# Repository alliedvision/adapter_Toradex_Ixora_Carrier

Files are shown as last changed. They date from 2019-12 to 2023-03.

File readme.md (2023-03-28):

# Allied Vision Adapter Board CSI-2 for Toradex Ixora Carrier Board

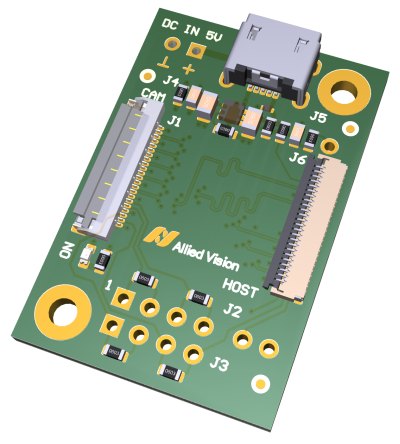
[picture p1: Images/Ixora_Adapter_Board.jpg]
toradex_ixora_adapter


This repository contains open hardware design files for an adapter board supporting the Allied Vision Alvium CSI-2 camera pinout to the Toradex Ixora Carrier Board, created by Allied Vision.
The board allows the user to interface with one Alvium MIPI CSI-2 compatible camera over a Flexible Flat Cable (FFC) connector.

You can also purchase the adapter from [Allied Vision](https://www.alliedvision.com/en/products/accessories/interface-connections/#!?cameraInterfacefilter=10) or from our [distributors](https://www.alliedvision.com/en/avt-locations/avt-distributors/).

## Getting Started

These instructions will get you a copy of the design files to make your own adapter boards for development and testing purposes. 
The board can be produced and assembled using the provided design files. Please take a look at the mechanical layers for more information regarding the PCB stackup recommended for fabrication. 

See our [website](https://www.alliedvision.com/en/support/technical-documentation/alvium-csi-2-documentation.html) for further documentation and installation guides of the finished boards.

### Prerequisites

* A running installation of Altium.
* A PCB producer & PCBA manufacturer or some soldering skills.
* One Toradex Ixora Carrier Board with an installed SOM
* One supported MIPI CSI-2 FPC cable
	* Allied Vision part numbers #12316, 12317, 12318
* [One Allied Vision Alvium CSI-2 camera](https://www.alliedvision.com/en/products/embedded-vision-cameras.html)

### Installing

Open the *CSI2-IXORA_Rev01.PrjPcb* project file in your Altium environment.

## Built With

* [Altium Designer 19](https://www.altium.com/altium-designer/de)
 
## License

This project is licensed under the MIT License - see the [LICENSE](LICENSE) file for details

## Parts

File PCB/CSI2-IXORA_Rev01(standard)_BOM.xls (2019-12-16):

 | Bill of Materials | CSI2-IXORA_Rev01
 | Project : | CSI2-IXORA
 | PCBA : |  | Revision : | 01
 | PCB : |  | Revision : | 01
 | Variant : | standard
 | Schematic : | CSI2-IXORA_Rev01 | Schematic.pdf
 | Placement : | CSI2-IXORA_Rev01 | Overlay.pdf
 | Report Date : | 26.11.2019 | 16:17
 | Alternative Parts :
Quantity | Designator | Comment | Footprint | Description | Manufacturer | Manufacturer Part Number | KHK Part Number
1 | C1 | 1n | C-0603_1.0 | Capacitor Ceramic SMD/0603/50V/X7R/10% | several | several | K8340038
2 | C2, C3 | 10u | C-0805_1.4 | Capacitor Ceramic SMD/0805/16V/X5R/10% | several | several | K8340151
1 | C4 | 100n | C-0603_1.0 | Capacitor Ceramic SMD/0603/50V/X7R/10% | several | several | K8340023
1 | D1 | GREEN | D-0603-LED | Chip LED green 430mcd | Würth | 150060GS75000 | 8172
1 | D2 | ESD9B5.0ST5G | D-SOD923 | DIODE TVS; 400W; 5.8-7.8V; BIDIRECT | ON Semiconductor | ESD9B5.0ST5G | 7250
1 | J1 | CON FFC22_Inverted | J-FH55-22S-0.5SH - Inverted Pins | FFC Connector 0.5mm shielded | Hirose | FH55-22S-0.5SH | 10357
2 | J2, J3 | NL | CON 1x4 RM2.54 | Stiftleiste; 1x4; 2.54mm; gerade
1 | J4 | NL | CON 1x2 RM2.54 | Stiftleiste; 1x2; 2.54mm; gerade
1 | J5 | USB 2.0 Typ B 90° | J-629105150521 | Micro USB 2.0 Typ B 90° | WE | 629 105 150 521 | 14360
1 | J6 | CON FFC24 | J-687124182122 | FFC Connector 0.5mm | Würth | 687124182122 | 14361
1 | LA1 | LABEL 7x7mm | PCB LABEL 7x7 | LABEL 7x7mm | several | several
3 | MRK1, MRK2, MRK3 | Marker Single Layer | PCB_Marker_Pad_top | Position Marker for PCBs
1 | PCB1 | 14276-01 |  | PCB ML04 | several | 14276-01 | 14276-01
1 | R1 | 3k3 | R-0603_0.6 | Standard Resistor SMD/0603/1%/100mW/TK100 | several | several | K8250070
1 | R2 | 1M | R-0603_0.6 | Standard Resistor SMD/0603/1%/100mW/TK100 | several | several | K8250058
4 | R3, R4, R6, R7 | 0R0 | R-0603_0.6 | Standard Resistor SMD/0603/1%/100mW/TK200, Standard Resistor SMD/0603/1%/100mW/TK100 | several | several | K8250041
1 | R5 | 51k | R-0603_0.6 | Standard Resistor SMD/0603/1%/100mW/TK100 | several | several | K8250156
1 | R8 | 270k | R-0603_0.6 | Standard Resistor SMD/0603/1%/100mW/TK100 | several | several | K8250170
2 | R9, R10 | NL | R-0603_0.6 | Standard Resistor SMD/0603/1%/100mW/TK200
1 | U1 | TPS25200DRVT | IC-DFN06_2.0x2.0x0.8 | IC/PWR/LOADSW;2V5-6V5;2A5;0R099/6-WDFN/2x2x0.8mm | Texas Instruments | TPS25200DRVT | 14277

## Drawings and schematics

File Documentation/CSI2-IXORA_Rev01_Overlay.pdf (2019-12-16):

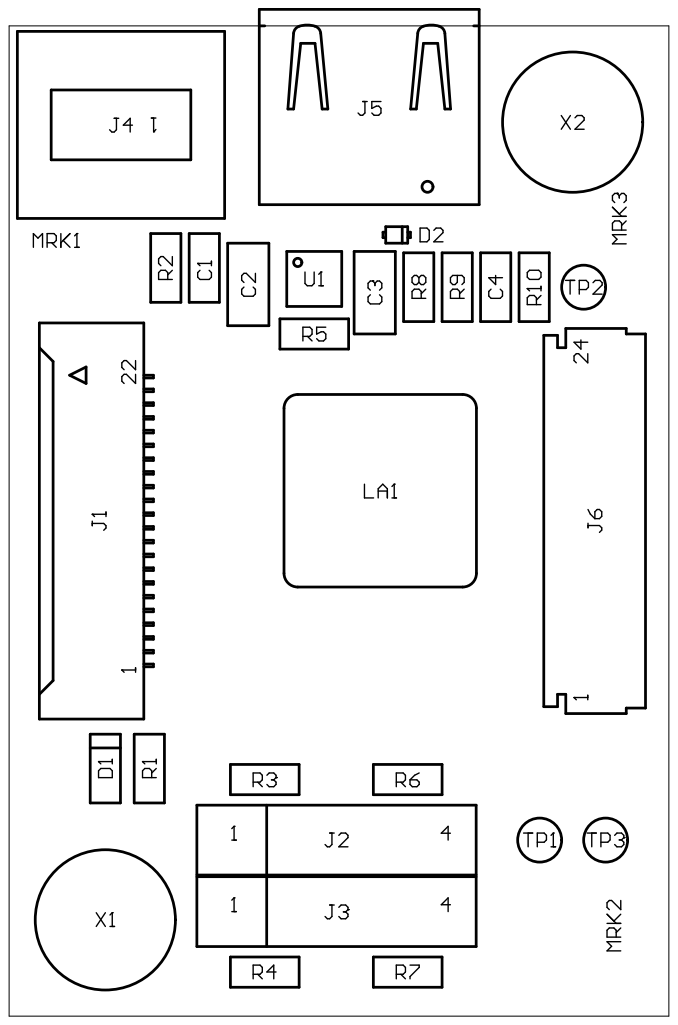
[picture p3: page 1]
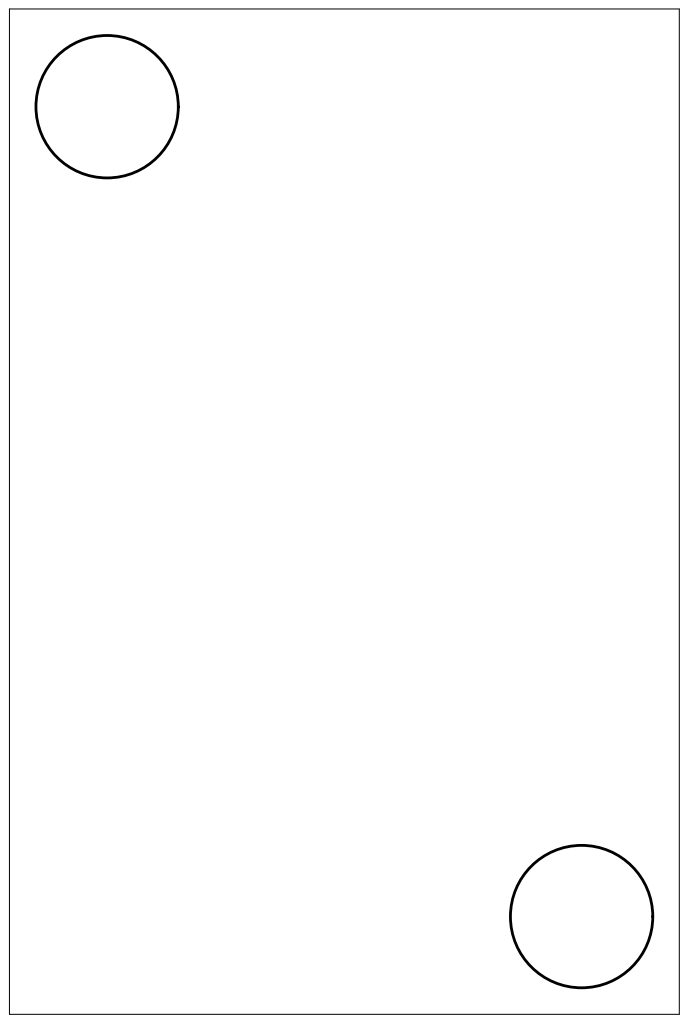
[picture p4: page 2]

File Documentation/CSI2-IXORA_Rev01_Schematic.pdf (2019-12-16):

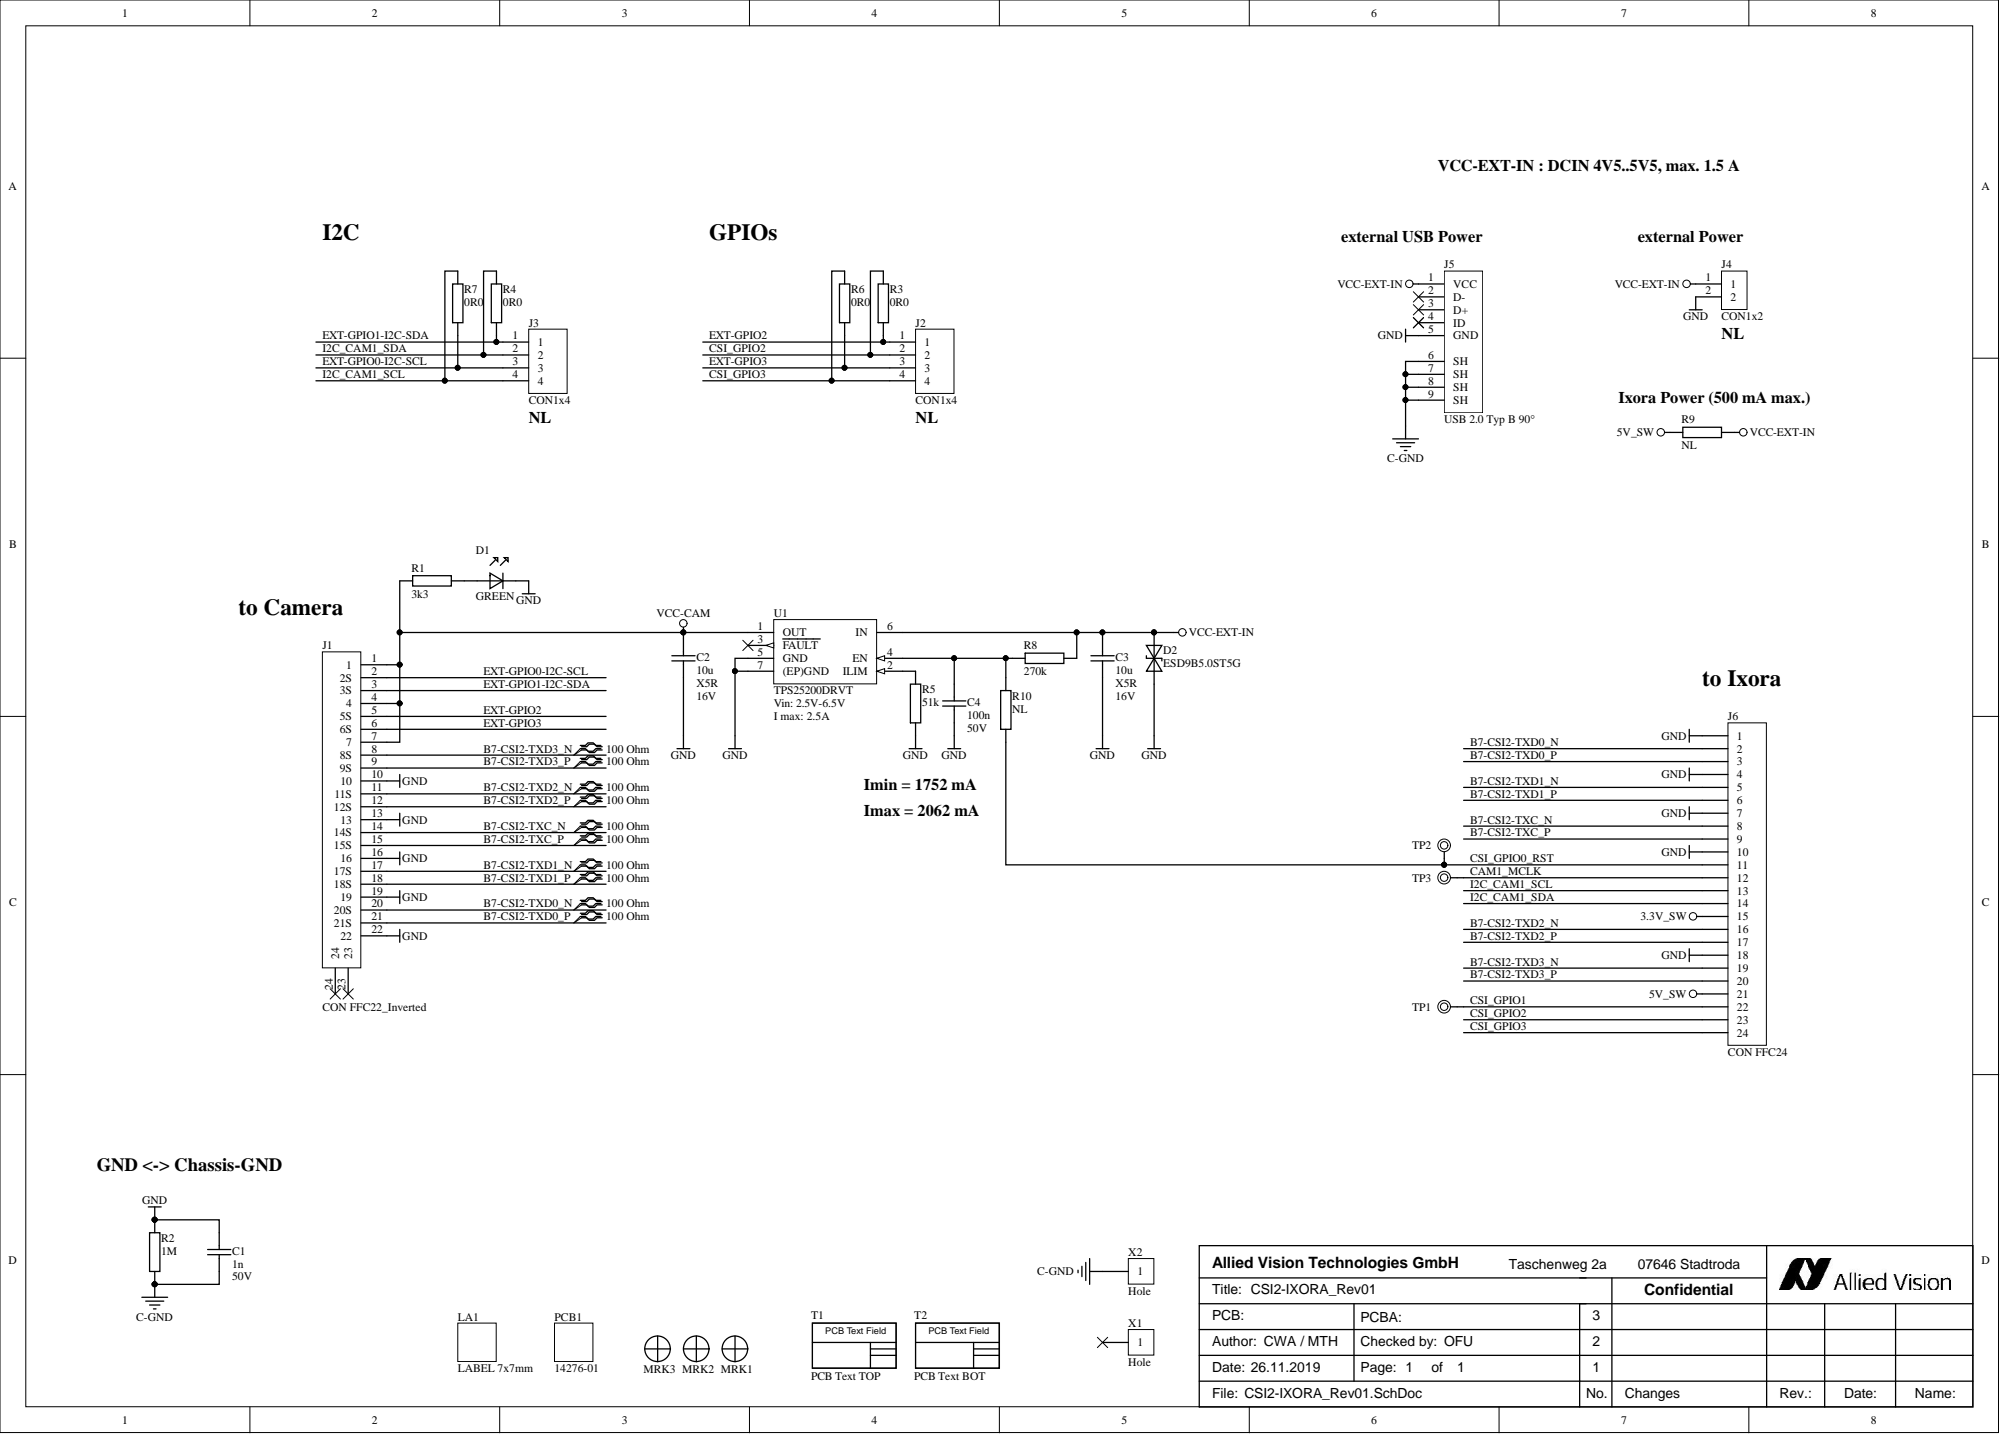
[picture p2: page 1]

VCC-EXT-IN : DCIN 4V5..5V5, max. 1.5 A

SH 7
SH 8

Ixora Power (500 mA max.)

Allied Vision Technologies GmbH Taschenweg 2a 07646 Stadtroda

CSI2-IXORA_Rev01 Title: | Confidential

Date: 26.11.2019 | 1

File: CSI2-IXORA_Rev01.SchDoc | No. | Changes | Rev.: | Date: | Name:
